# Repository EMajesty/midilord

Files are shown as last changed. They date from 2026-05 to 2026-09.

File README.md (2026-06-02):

# midilord

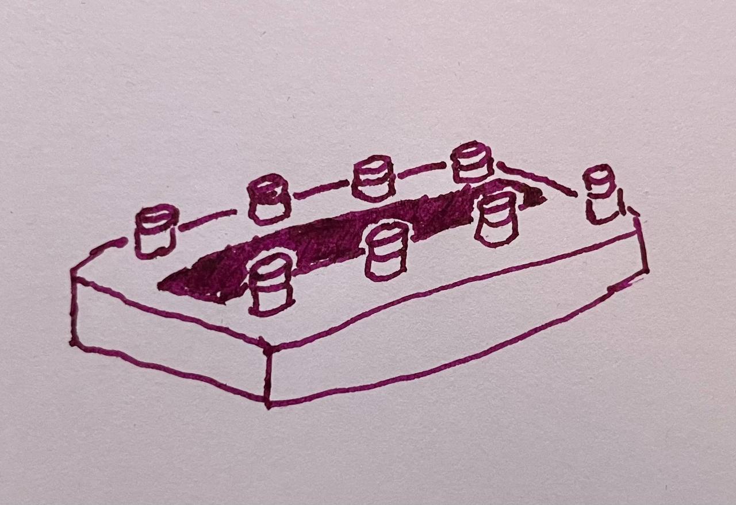
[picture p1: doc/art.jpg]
midilord


MIDI controller pedal built on ESP32-S3.

## Hardware

- 8 footswitches
- 4×40 character LCD (ST7066U, 4-bit parallel)
- 1 MIDI IN, multiple MIDI OUTs
- USB MIDI (native ESP32-S3 USB OTG port)
- 9V pedal power, regulated to 5V and 3.3V logic

### LCD pinout (XNY4004A, 18-pin)

| Pin | Function |
|-----|---|
| 1 | DB0 |
| 2 | DB1 |
| 3 | DB2 |
| 4 | DB3 |
| 5 | DB4 |
| 6 | DB5 |
| 7 | DB6 |
| 8 | DB7 |
| 9 | E1 |
| 10 | R/W |
| 11 | RS |
| 12 | Vo (contrast) |
| 13 | VSS (GND) |
| 14 | VDD (+5V) |
| 15 | E2 |
| 16 | NC |
| 17 | Backlight + |
| 18 | Backlight - |

## Planned features

- Morningstar-inspired function set
- Presets and banks (16 banks × 8 presets)
- Tap tempo
- Web server for preset and config editing

[LCD Datasheet](https://www.crystalfontz.com/products/document/931/CFAH4004A-YYH-JTDatasheetRelease2021-11-03.pdf)
[APA106](https://cdn.sparkfun.com/datasheets/Components/LED/COM-12877.pdf)

```
x0123456789012345678901234567890123456789
0 [Preset]  [Preset]  [Preset]  [Preset]
1
2
3 [Preset]  [Preset]  [Preset]  [Preset]
```

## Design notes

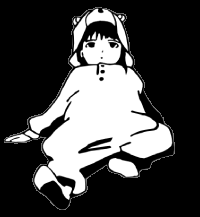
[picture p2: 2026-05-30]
hardware/art/lain.bmp

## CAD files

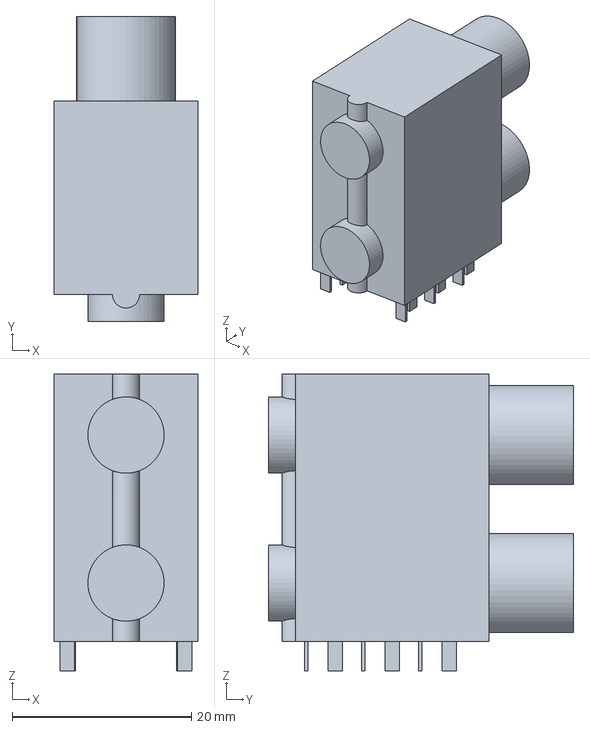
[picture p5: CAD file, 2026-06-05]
hardware/3d/CK635-037.step
16.0 x 34.0 x 33.1 mm

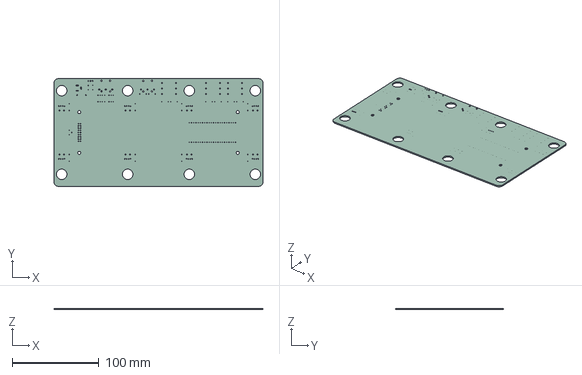
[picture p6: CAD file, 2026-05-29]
hardware/core/core.step
241.3 x 124.5 x 1.51 mm

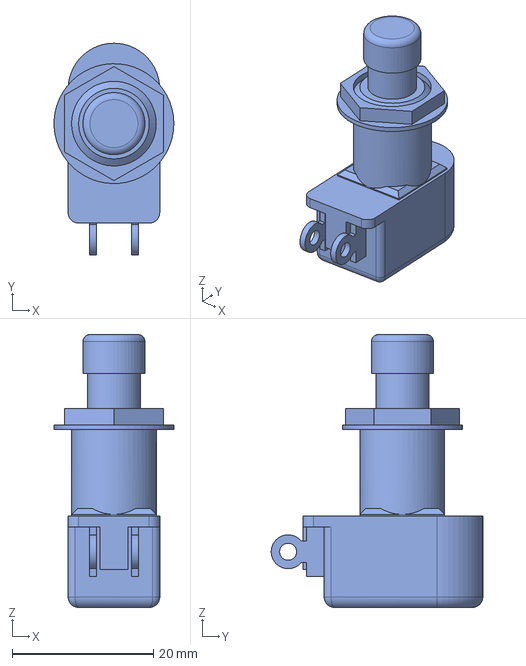
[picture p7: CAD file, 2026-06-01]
hardware/3d/Footswitch.step
17.0 x 30.0 x 38.7 mm

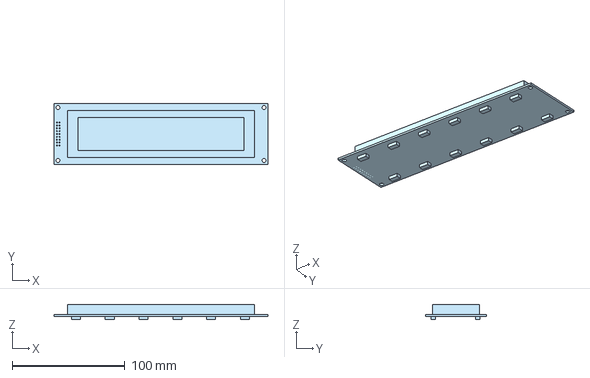
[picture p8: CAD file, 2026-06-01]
hardware/3d/4004A.step
190.0 x 54.0 x 13.3 mm

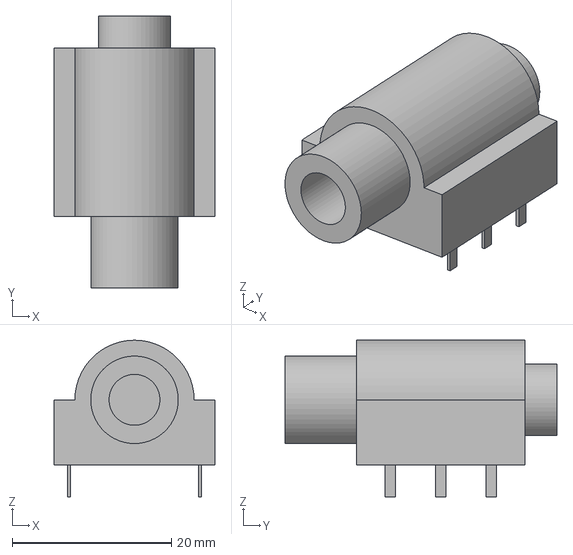
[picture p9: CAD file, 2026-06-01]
hardware/3d/CK635-006.step
20.2 x 34.2 x 19.7 mm

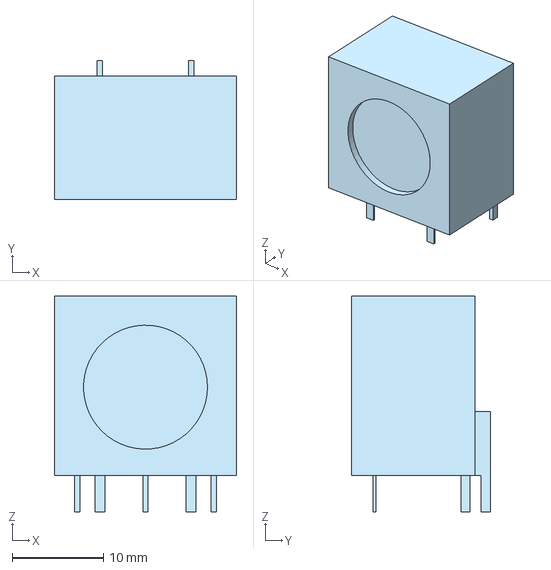
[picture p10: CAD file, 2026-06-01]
hardware/3d/DIN5_180.step
20.0 x 15.2 x 23.7 mm

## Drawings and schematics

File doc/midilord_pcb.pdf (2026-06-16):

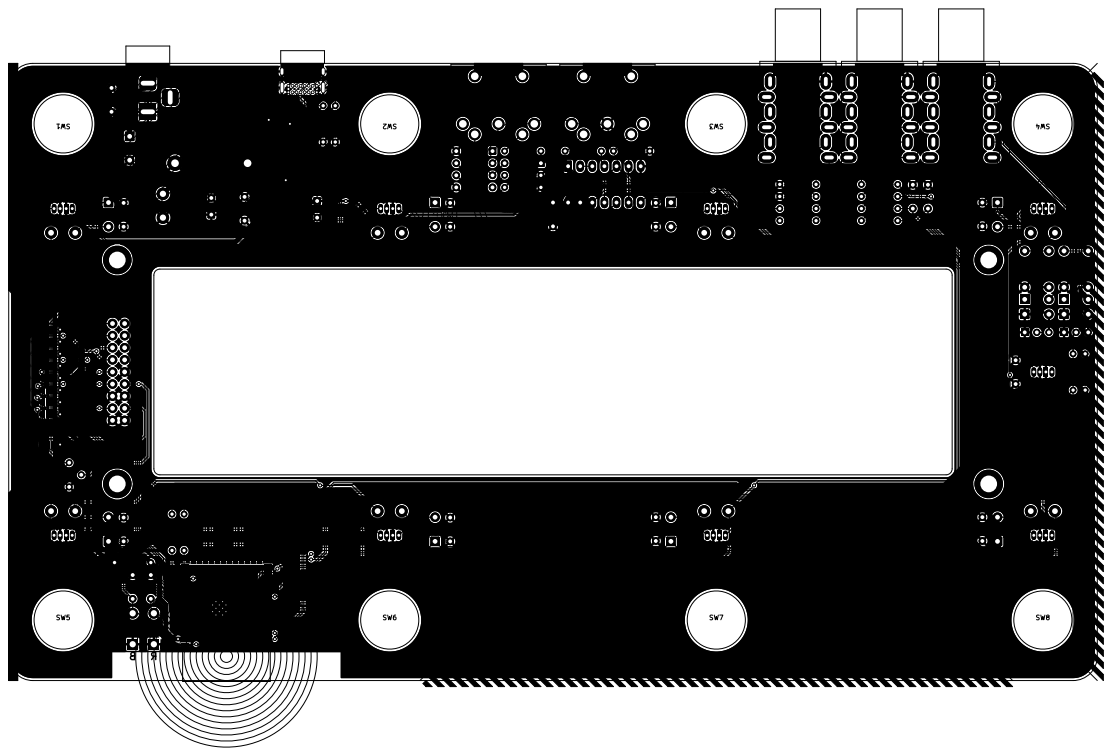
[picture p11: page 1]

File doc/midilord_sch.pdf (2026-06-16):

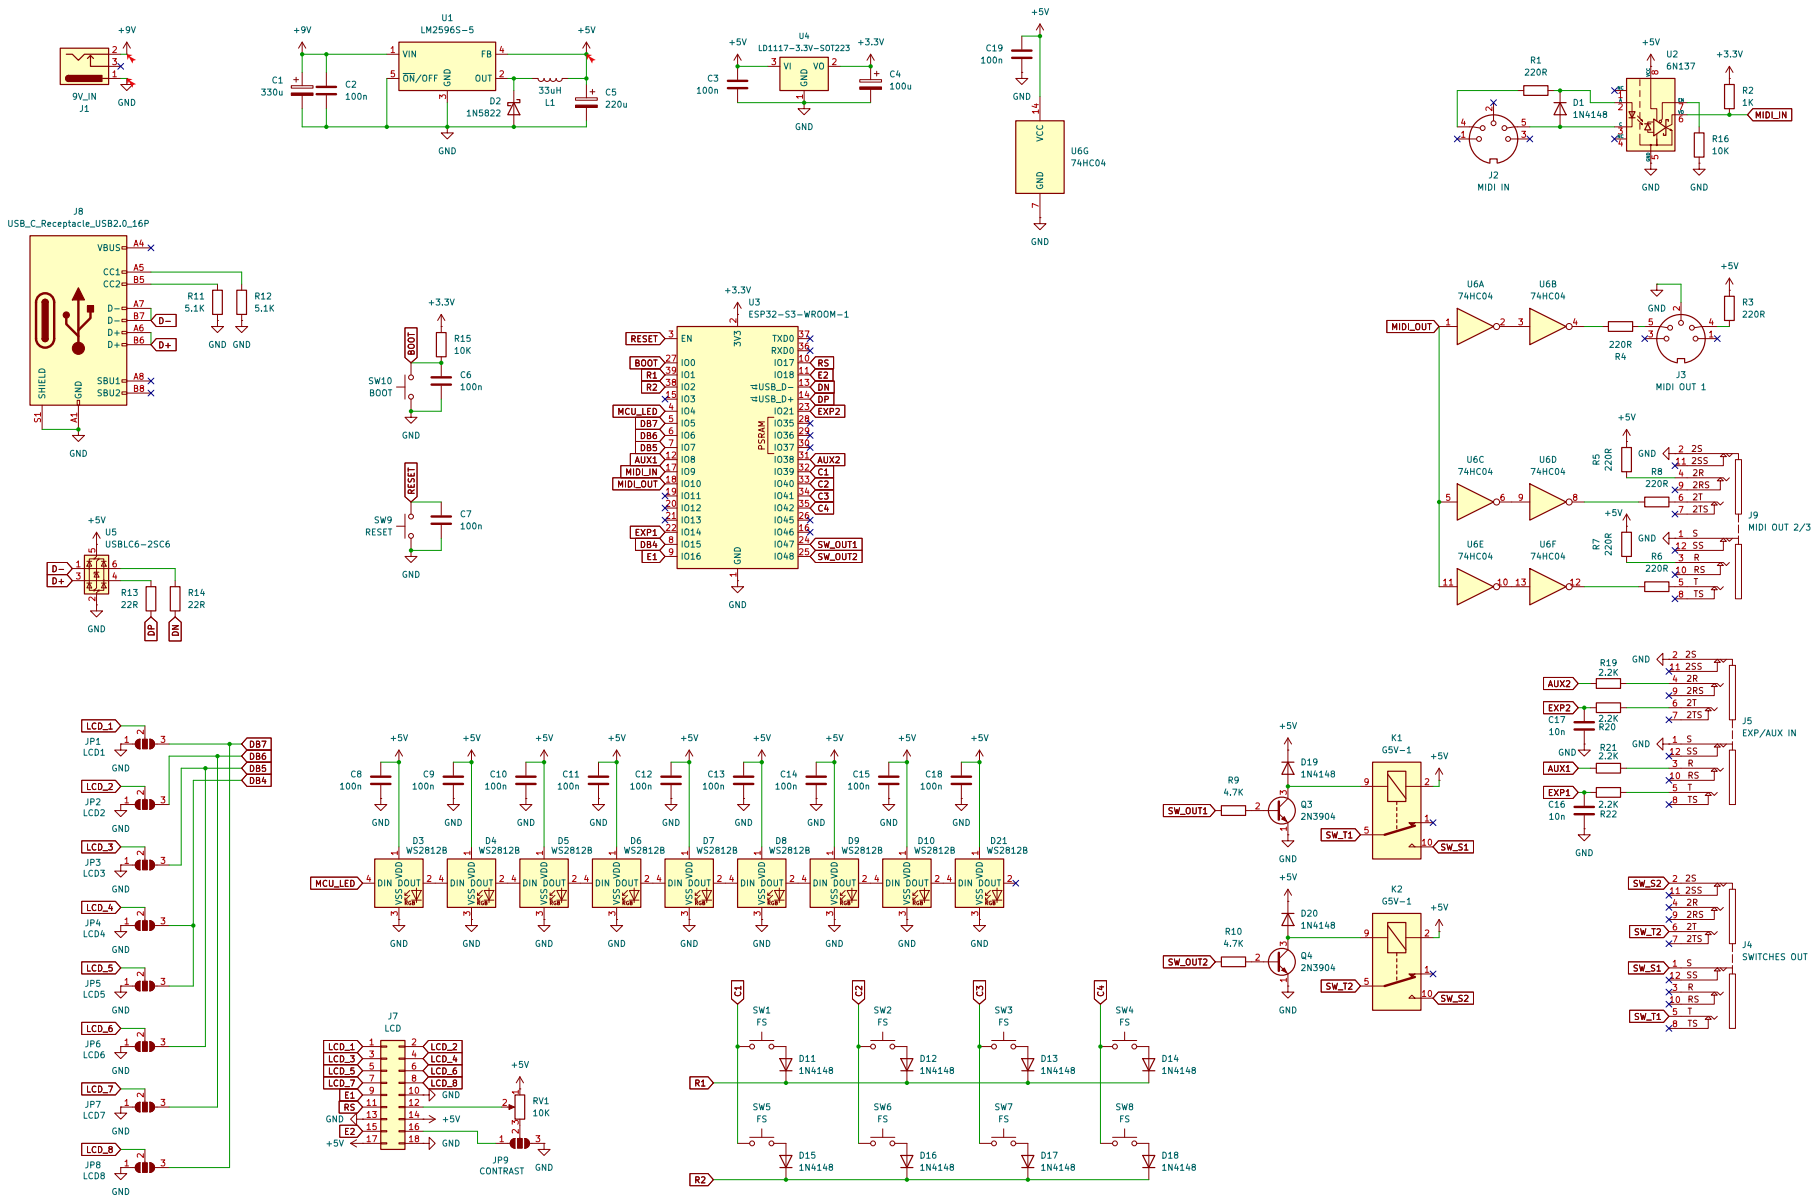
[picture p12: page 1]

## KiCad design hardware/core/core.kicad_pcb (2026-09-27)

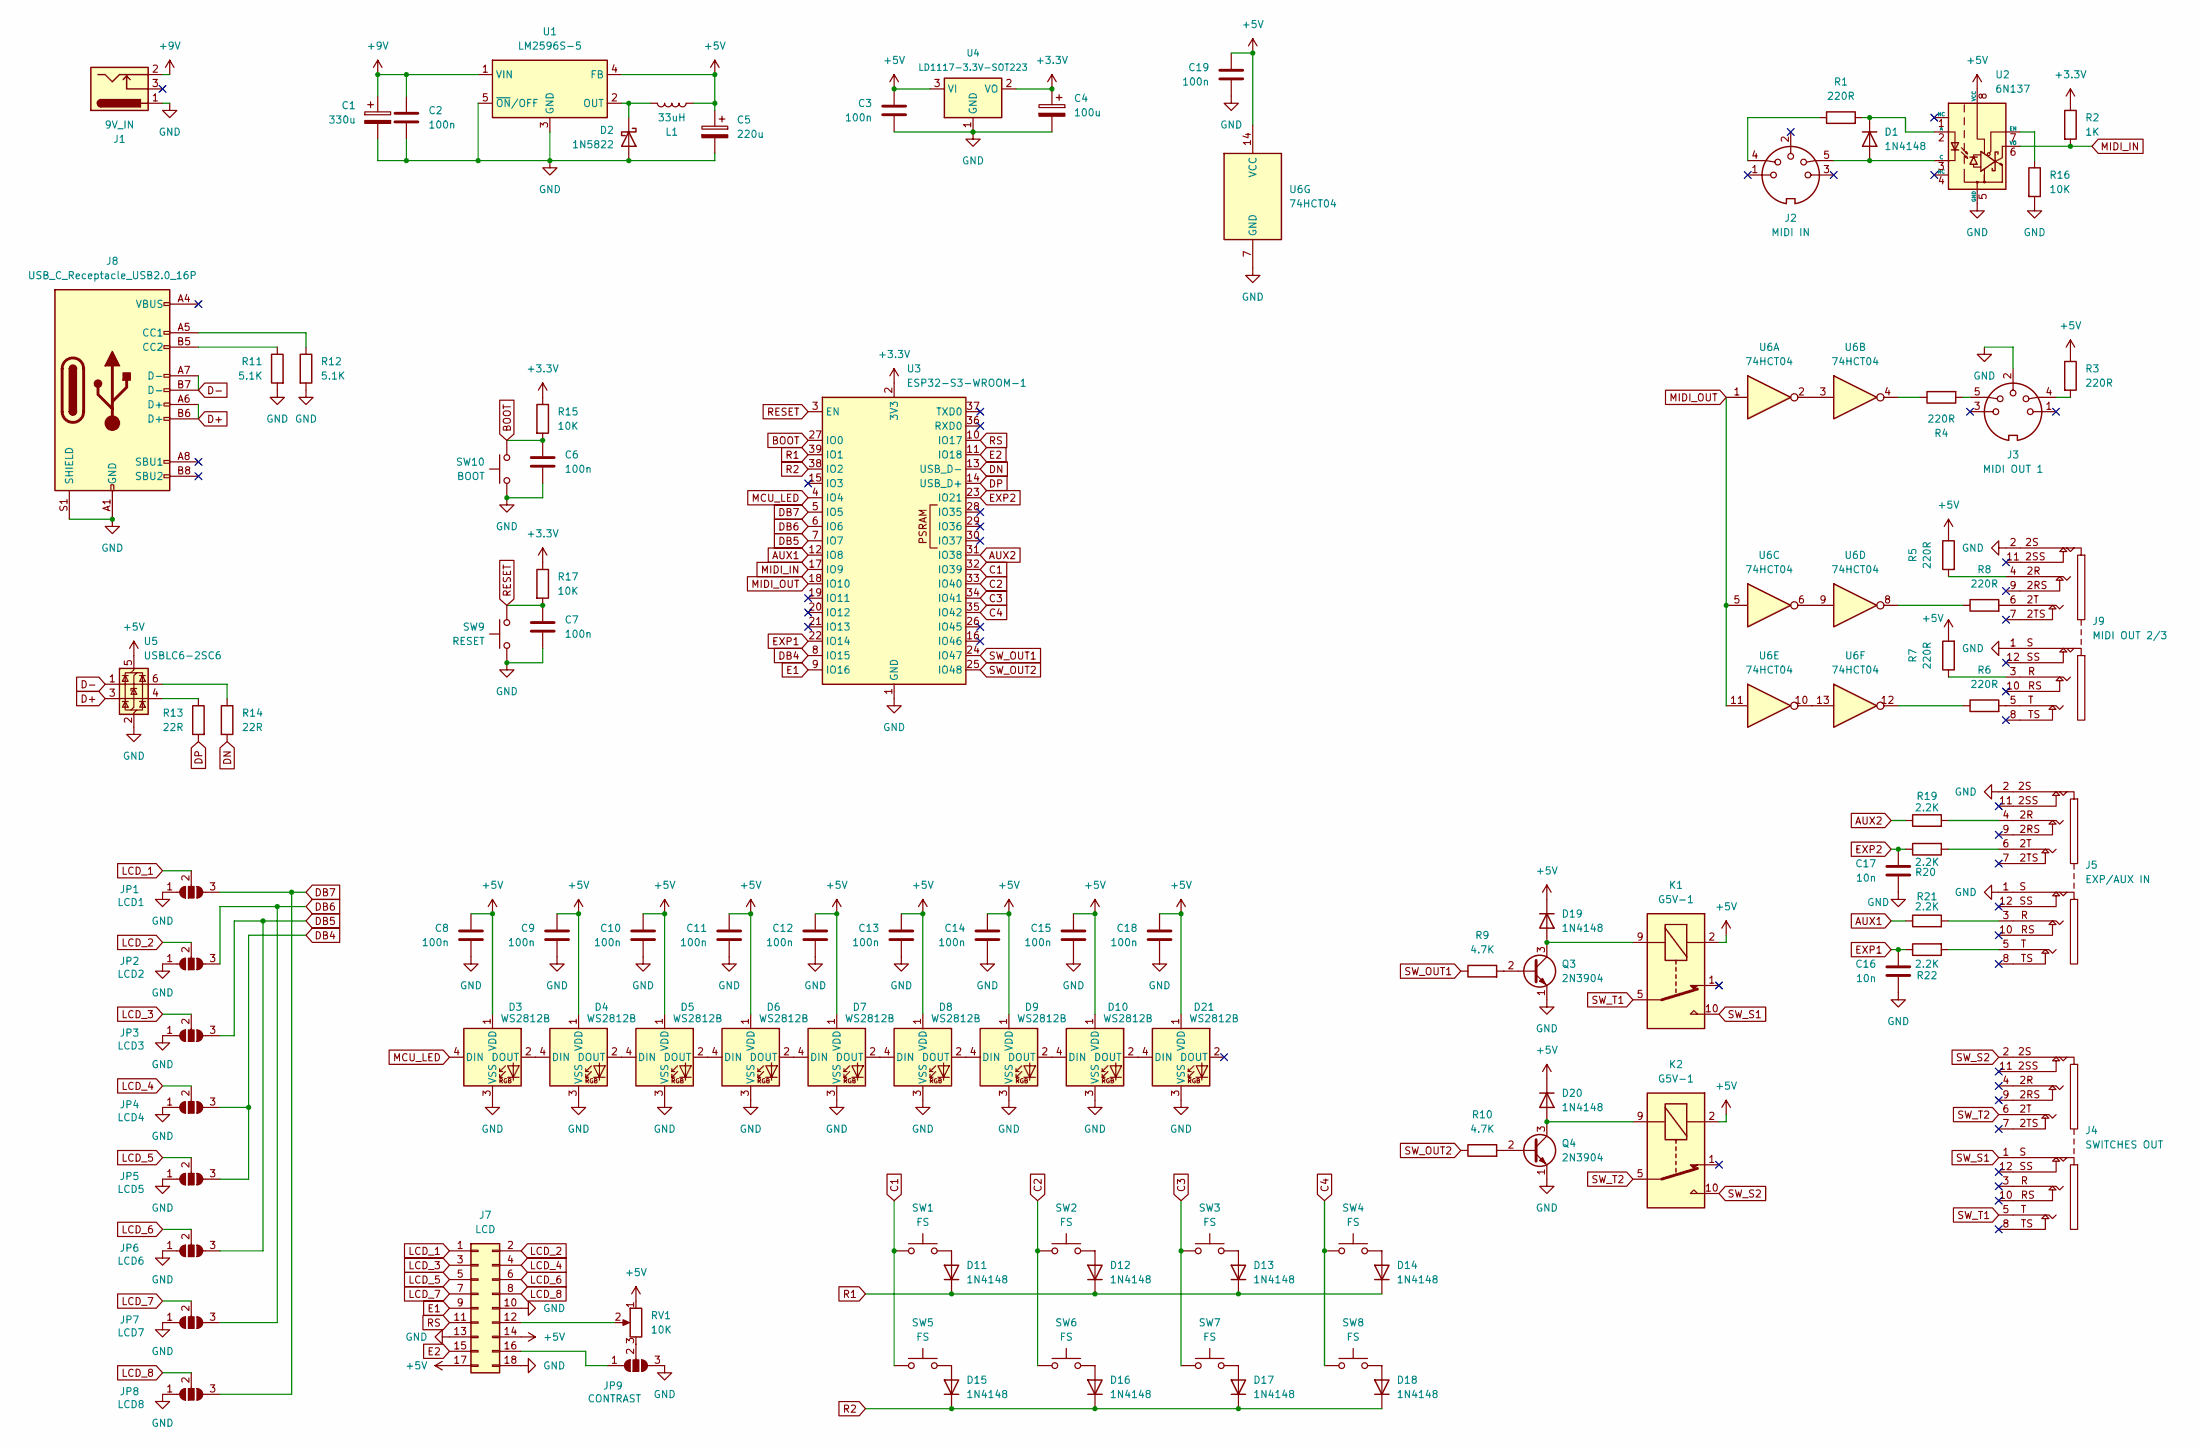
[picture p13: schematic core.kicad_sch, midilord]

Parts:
C1: 330u; CP_Radial_D10.0mm_P5.00mm
C2, C3, C6, C7, C8, C9, C10, C11, C12, C13, C14, C15, C18, C19: 100n; C_Rect_L7.0mm_W2.5mm_P5.00mm
C4: 100u; CP_Radial_D8.0mm_P3.50mm
C5: 220u; CP_Radial_D8.0mm_P3.50mm
C16, C17: 10n; C_Rect_L7.0mm_W2.5mm_P5.00mm
D1: 1N4148; D_DO-35_SOD27_P7.62mm_Horizontal
D2: 1N5822; D_DO-201AD_P15.24mm_Horizontal
D3, D4, D5, D6, D7, D8, D9, D10, D21: WS2812B; APA106
D11, D12, D13, D14, D15, D16, D17, D18, D19, D20: 1N4148; D_T-1_P5.08mm_Horizontal
J1: 9V_IN; BarrelJack_Horizontal
J2: MIDI IN; DIN5_180
J3: MIDI OUT 1; DIN5_180
J4: SWITCHES OUT; CK635-037
J5: EXP/AUX IN; CK635-037
J7: LCD; 4004A
J8: USB_C_Receptacle_USB2.0_16P; USB_C_Receptacle_GCT_USB4085
J9: MIDI OUT 2/3; CK635-037
JP1: LCD1; SolderJumper-3_P1.3mm_Open_RoundedPad1.0x1.5mm
JP2: LCD2; SolderJumper-3_P1.3mm_Open_RoundedPad1.0x1.5mm
JP3: LCD3; SolderJumper-3_P1.3mm_Open_RoundedPad1.0x1.5mm
JP4: LCD4; SolderJumper-3_P1.3mm_Open_RoundedPad1.0x1.5mm
JP5: LCD5; SolderJumper-3_P1.3mm_Open_RoundedPad1.0x1.5mm
JP6: LCD6; SolderJumper-3_P1.3mm_Open_RoundedPad1.0x1.5mm
JP7: LCD7; SolderJumper-3_P1.3mm_Open_RoundedPad1.0x1.5mm
JP8: LCD8; SolderJumper-3_P1.3mm_Open_RoundedPad1.0x1.5mm
JP9: CONTRAST; SolderJumper-3_P1.3mm_Open_RoundedPad1.0x1.5mm
K1, K2: G5V-1; Relay_SPDT_Omron_G5V-1
L1: 33uH; L_Radial_D9.5mm_P5.00mm_Fastron_07HVP
Q3, Q4: 2N3904; TO-92_Inline_Wide
R1, R3, R4, R5, R6, R7, R8: 220R; R_Axial_DIN0204_L3.6mm_D1.6mm_P7.62mm_Horizontal
R2: 1K; R_Axial_DIN0204_L3.6mm_D1.6mm_P7.62mm_Horizontal
R9, R10: 4.7K; R_Axial_DIN0204_L3.6mm_D1.6mm_P7.62mm_Horizontal
R11, R12: 5.1K; R_Axial_DIN0204_L3.6mm_D1.6mm_P7.62mm_Horizontal
R13, R14: 22R; R_Axial_DIN0204_L3.6mm_D1.6mm_P7.62mm_Horizontal
R15, R16, R17: 10K; R_Axial_DIN0204_L3.6mm_D1.6mm_P7.62mm_Horizontal
R19, R20, R21, R22: 2.2K; R_Axial_DIN0204_L3.6mm_D1.6mm_P7.62mm_Horizontal
RV1: 10K; Potentiometer_Bourns_3296Y_Vertical
SW1, SW2, SW3, SW4, SW5, SW6, SW7, SW8: FS; Footswitch
SW9: RESET; SW_PUSH_1P1T_6x3.5mm_H5.0_APEM_MJTP1250
SW10: BOOT; SW_PUSH_1P1T_6x3.5mm_H5.0_APEM_MJTP1250
U1: LM2596S-5; TO-263-5_TabPin3
U2: 6N137; DIP-8_W7.62mm
U3: ESP32-S3-WROOM-1
U4: LD1117-3.3V-SOT223; SOT-223; Part Number LD1117S33CTR
U5: USBLC6-2SC6; SOT-23-6
U6: 74HCT04; DIP-14_W7.62mm_Socket_LongPads

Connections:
+3.3V: C4.1, R2.1, R15.1, R17.1, U3.2 (3V3), U4.2 (VO)
+5V: C3.1, C5.1, C8.1, C9.1, C10.1, C11.1, C12.1, C13.1, C14.1, C15.1, C18.1, C19.1, D3.1 (VDD), D4.1 (VDD), D5.1 (VDD), D6.1 (VDD), D7.1 (VDD), D8.1 (VDD), D9.1 (VDD), D10.1 (VDD), D19.1 (K), D20.1 (K), D21.1 (VDD), J7.14, J7.17, K1.2, K2.2, L1.2, R3.1, R5.1, R7.2, RV1.1, U1.4 (FB), U2.8 (VCC), U4.3 (VI), U5.5 (VBUS), U6.14 (VCC)
+9V: C1.1, C2.1, J1.2, U1.1 (VIN)
AUX1: R21.1, U3.12 (IO8)
AUX2: R19.1, U3.31 (IO38)
BOOT: C6.1, R15.2, SW10.2, U3.27 (IO0)
C1: SW1.2, SW5.1, U3.32 (IO39)
C2: SW2.2, SW6.1, U3.33 (IO40)
C3: SW3.1, SW7.2, U3.34 (IO41)
C4: SW4.1, SW8.2, U3.35 (IO42)
D+: J8.A6 (D+), J8.B6 (D+), U5.3 (I/O2)
D-: J8.A7 (D-), J8.B7 (D-), U5.1 (I/O1)
DB4: JP4.3 (B), JP5.3 (B), U3.8 (IO15)
DB5: JP3.3 (B), JP6.3 (B), U3.7 (IO7)
DB6: JP2.3 (B), JP7.3 (B), U3.6 (IO6)
DB7: JP1.3 (B), JP8.3 (B), U3.5 (IO5)
DN: R14.2, U3.13 (USB_D-)
DP: R13.2, U3.14 (USB_D+)
E1: J7.9, U3.9 (IO16)
E2: J7.15, U3.11 (IO18)
EXP1: C16.1, R22.1, U3.22 (IO14)
EXP2: C17.1, R20.1, U3.23 (IO21)
GND: C1.2, C2.2, C3.2, C4.2, C5.2, C6.2, C7.2, C8.2, C9.2, C10.2, C11.2, C12.2, C13.2, C14.2, C15.2, C16.2, C17.2, C18.2, C19.2, D2.2 (A), D3.3 (VSS), D4.3 (VSS), D5.3 (VSS), D6.3 (VSS), D7.3 (VSS), D8.3 (VSS), D9.3 (VSS), D10.3 (VSS), D21.3 (VSS), J1.1, J3.2, J5.1 (S), J5.2 (2S), J7.10, J7.13, J7.18, J8.A1 (GND), J8.A12 (GND), J8.B1 (GND), J8.B12 (GND), J8.S1 (SHIELD), J9.1 (S), J9.2 (2S), JP1.1 (A), JP2.1 (A), JP3.1 (A), JP4.1 (A), JP5.1 (A), JP6.1 (A), JP7.1 (A), JP8.1 (A), JP9.3 (B), Q3.1 (E), Q4.1 (E), R11.2, R12.2, R16.2, SW9.1, SW10.1, U1.3 (GND), U1.5 (~ON/OFF), U2.5 (GND), U3.1 (GND), U3.40 (GND), U3.41 (GND), U4.1 (GND), U5.2 (GND), U6.7 (GND)
LCD_1: J7.1, JP1.2 (C)
LCD_2: J7.2, JP2.2 (C)
LCD_3: J7.3, JP3.2 (C)
LCD_4: J7.4, JP4.2 (C)
LCD_5: J7.5, JP5.2 (C)
LCD_6: J7.6, JP6.2 (C)
LCD_7: J7.7, JP7.2 (C)
LCD_8: J7.8, JP8.2 (C)
MCU_LED: D3.4 (DIN), U3.4 (IO4)
MIDI_IN: R2.2, U2.6 (VO), U3.17 (IO9)
MIDI_OUT: U3.18 (IO10), U6.1, U6.5, U6.11
unnamed: D1.2 (A), J2.5, U2.3 (C)
unnamed: D1.1 (K), R1.2, U2.2 (A)
unnamed: D2.1 (K), L1.1, U1.2 (OUT)
unnamed: D3.2 (DOUT), D4.4 (DIN)
unnamed: D4.2 (DOUT), D5.4 (DIN)
unnamed: D5.2 (DOUT), D6.4 (DIN)
unnamed: D6.2 (DOUT), D7.4 (DIN)
unnamed: D7.2 (DOUT), D8.4 (DIN)
unnamed: D8.2 (DOUT), D9.4 (DIN)
unnamed: D9.2 (DOUT), D10.4 (DIN)
unnamed: D10.2 (DOUT), D21.4 (DIN)
unnamed: D11.2 (A), SW1.1
unnamed: D12.2 (A), SW2.1
unnamed: D13.2 (A), SW3.2
unnamed: D14.2 (A), SW4.2
unnamed: D15.2 (A), SW5.2
unnamed: D16.2 (A), SW6.2
unnamed: D17.2 (A), SW7.1
unnamed: D18.2 (A), SW8.1
unnamed: D19.2 (A), K1.9, Q3.3 (C)
unnamed: D20.2 (A), K2.9, Q4.3 (C)
unnamed: J2.4, R1.1
unnamed: J3.4, R3.2
unnamed: J3.5, R4.2
unnamed: J5.4 (2R), R19.2
unnamed: J5.6 (2T), R20.2
unnamed: J5.3 (R), R21.2
unnamed: J5.5 (T), R22.2
unnamed: J7.12, RV1.2
unnamed: J7.16, JP9.1 (A)
unnamed: J8.A5 (CC1), R12.1
unnamed: J8.B5 (CC2), R11.1
unnamed: J9.4 (2R), R5.2
unnamed: J9.6 (2T), R8.2
unnamed: J9.3 (R), R7.1
unnamed: J9.5 (T), R6.2
unnamed: JP9.2 (C), RV1.3
unnamed: Q3.2 (B), R9.2
unnamed: Q4.2 (B), R10.2
unnamed: R4.1, U6.4
unnamed: R6.1, U6.12
unnamed: R8.1, U6.8
unnamed: R13.1, U5.4 (I/O2)
unnamed: R14.1, U5.6 (I/O1)
unnamed: R16.1, U2.7 (EN)
unnamed: U6.2, U6.3
unnamed: U6.6, U6.9
unnamed: U6.10, U6.13
R1: D11.1 (K), D12.1 (K), D13.1 (K), D14.1 (K), U3.39 (IO1)
R2: D15.1 (K), D16.1 (K), D17.1 (K), D18.1 (K), U3.38 (IO2)
RESET: C7.1, R17.2, SW9.2, U3.3 (EN)
RS: J7.11, U3.10 (IO17)
SW_OUT1: R9.1, U3.24 (IO47)
SW_OUT2: R10.1, U3.25 (IO48)
SW_S1: J4.1 (S), K1.10
SW_S2: J4.2 (2S), K2.10
SW_T1: J4.5 (T), K1.5, K1.6
SW_T2: J4.6 (2T), K2.5, K2.6

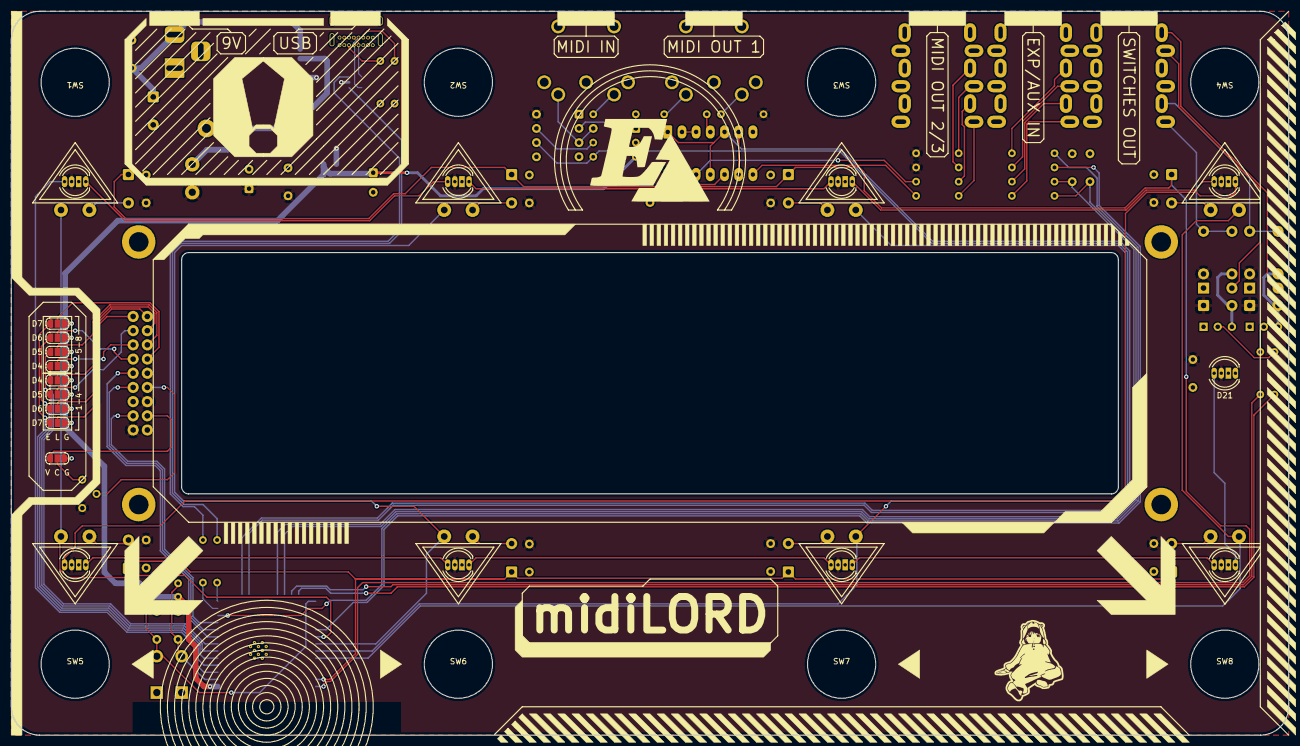
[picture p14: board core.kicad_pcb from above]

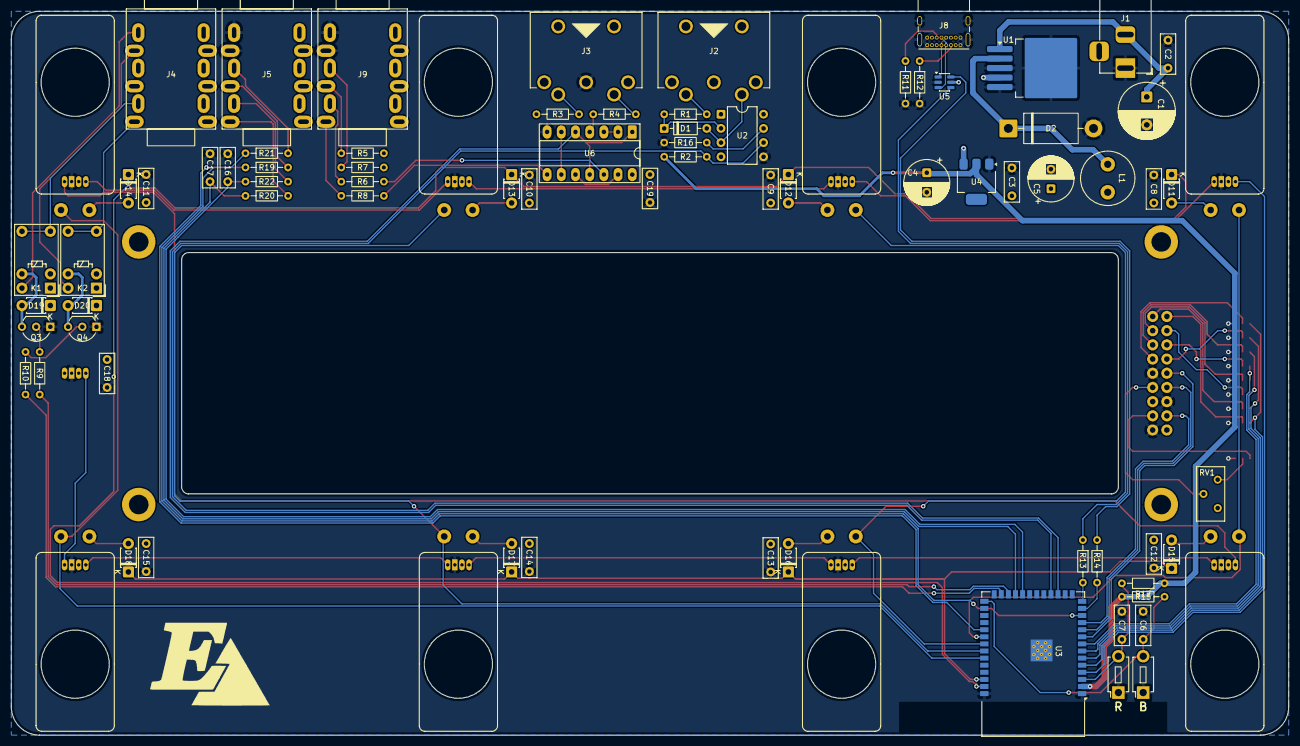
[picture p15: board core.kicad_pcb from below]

Board: 2 copper layers, 228.6 x 129.5 mm, 100 parts (73 on the bottom side), 92 nets.

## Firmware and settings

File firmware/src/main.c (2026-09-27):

#include <zephyr/drivers/gpio.h>
#include <zephyr/kernel.h>
#include <zephyr/sys/printk.h>

#define GPIO_SPEC(node_id, prop, idx)                                          \
    GPIO_DT_SPEC_GET_BY_IDX(node_id, prop, idx),

#define SWITCHES_NODE DT_PATH(switches)

static const struct gpio_dt_spec rows[] = {
    DT_FOREACH_PROP_ELEM(SWITCHES_NODE, row_gpios, GPIO_SPEC)};
static const struct gpio_dt_spec cols[] = {
    DT_FOREACH_PROP_ELEM(SWITCHES_NODE, col_gpios, GPIO_SPEC)};

int main(void) {
    for (int i = 0; i < ARRAY_SIZE(rows); i++) {
        if (!device_is_ready(rows[i].port)) {
            return 0;
        }
    }

    for (int i = 0; i < ARRAY_SIZE(cols); i++) {
        if (!device_is_ready(cols[i].port)) {
            return 0;
        }
    }

    for (int i = 0; i < ARRAY_SIZE(rows); i++) {
        gpio_pin_configure_dt(&rows[i],
                              GPIO_INPUT); // initialized as inactive for now
    }

    for (int i = 0; i < ARRAY_SIZE(cols); i++) {
        gpio_pin_configure_dt(&cols[i], GPIO_INPUT | GPIO_PULL_UP);
    }

    uint8_t raw_state;

    while (1) {
        raw_state = 0;

        for (int i = 0; i < ARRAY_SIZE(rows); i++) {
            for (int j = 0; j < ARRAY_SIZE(rows); j++) {
                if (i == j) {
                    gpio_pin_configure_dt(&rows[j], GPIO_OUTPUT_LOW);
                } else {
                    gpio_pin_configure_dt(&rows[j], GPIO_INPUT);
                }
            }

            k_busy_wait(10);

            for (int j = 0; j < ARRAY_SIZE(cols); j++) {
                if (gpio_pin_get_dt(&cols[j]) == 0) {
                    raw_state |= (1U << (i * ARRAY_SIZE(cols) + j));
                }
            }
        }

        for (int i = 7; i >= 0; i--) {
            printk("%d", (raw_state >> i) & 1);
        }

        printk("\n");

        for (int i = 0; i < ARRAY_SIZE(rows); i++) {
            gpio_pin_configure_dt(&rows[i],
                                  GPIO_INPUT); // inactivate outputs again
        }

        k_busy_wait(100000);
    }

    return 0;
}

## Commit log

2024-07-11 wiring revision
2024-07-13 switches work, library change
2024-08-23 disable waiting for usb mounting
2025-08-16 add pcb files, reorganize
    [midilord.kicad_pcb, midilord.kicad_sch]
2025-08-17 pcb proge
    [midilord.kicad_sch]
2026-05-04 Reorganize repo: add README, remove firmware and pcb files
    [midilord.kicad_pcb, midilord.kicad_sch]
2026-05-26 Prompt is too long
    [core.kicad_pcb, core.kicad_sch, panel.kicad_pcb]
2026-05-30 Reduce PCB to 2-layer stackup and update design rules
    [core.kicad_pcb, core.kicad_sch]
2026-05-30 Add PCB/schematic PDFs and hardware bitmap asset
2026-05-31 Add WS2812B LED support, update LCD pinout docs, and revise PCB nets
    [core.kicad_pcb, core.kicad_sch]
2026-05-31 Add APA106 LED datasheet link to README
2026-05-31 Update power spec to include 5V regulation stage
2026-06-01 Add EMaj logo SVG and silkscreen artwork to PCB
    [core.kicad_pcb, core.kicad_sch]
2026-06-01 Add LCD preset layout diagram and DIN5-180 connector 3D model
    [DIN5-180 - DIN5-180.step, Footswitch - Footswitch.step, Jack - Jack.step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]
2026-06-01 Add LCD and LED driver modules, refactor main.cpp
2026-06-02 Add vegas mode stubs and update LED count to 8
    [core.kicad_pcb]
2026-06-04 Reposition silkscreen logos, add mounting hole circles, remove channel number labels
    [core.kicad_pcb]
2026-06-04 Adjust connector positions and reroute nearby traces
    [core.kicad_pcb]
2026-06-04 Move footswitch silkscreen circle to Dwgs.User layer
    [core.kicad_pcb]
2026-06-05 Add event system, switch matrix, MIDI outputs, and LED helpers
    [4004A.step, CK635-006.step, CK635-037.step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]
2026-06-05 Replace footswitch connector nets with aux/expression nets and renumber
    [core.kicad_pcb, core.kicad_sch]
2026-06-09 Add LittleFS bank storage, enable MIDI ports, and split LED clear/set
2026-06-09 Update PCB layout with revised nets and add D21 WS2812B LED
    [core.kicad_pcb, core.kicad_sch]
2026-06-16 Update PCB layout and fix DRC warnings for unconnected pins
    [core.kicad_pcb, core.kicad_sch]
2026-09-26 Migrate firmware scaffold from PlatformIO to Zephyr
    [core.kicad_pcb]
2026-09-26 Add ESP32-S3 Zephyr build, flash, and console setup
2026-09-26 Pin monitor to the ESP serial device
2026-09-27 Add switch matrix GPIO configuration and hardware updates
    [core.kicad_pcb, core.kicad_sch]
2026-09-27 Implement GPIO switch matrix scanning
